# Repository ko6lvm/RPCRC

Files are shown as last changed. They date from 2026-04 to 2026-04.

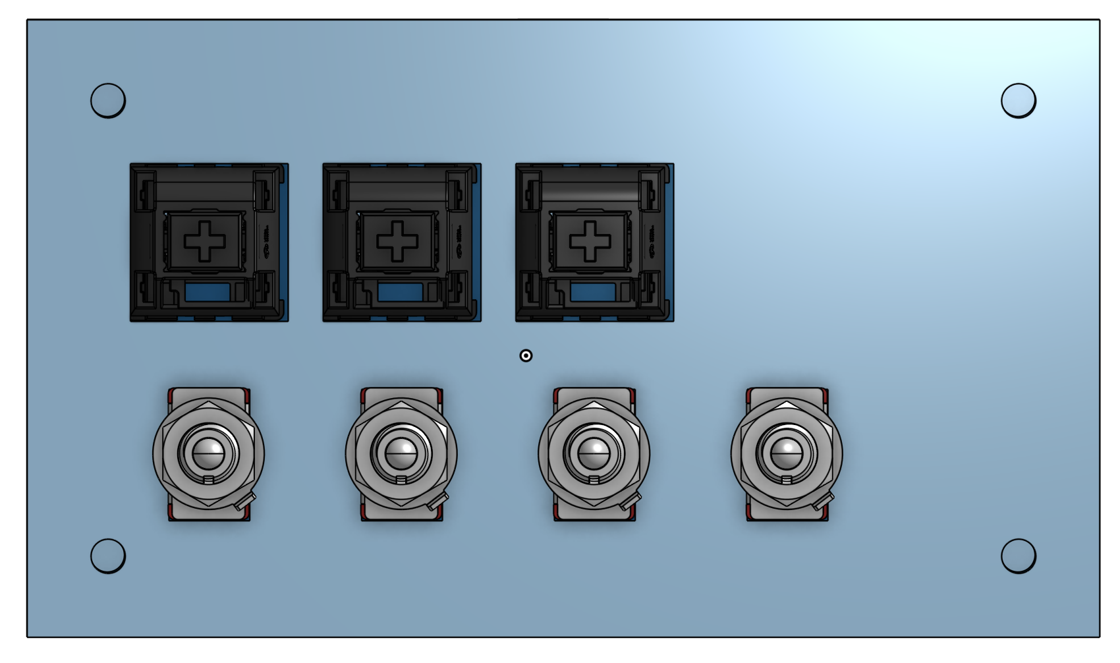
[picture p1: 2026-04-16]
img/assembly_top.png

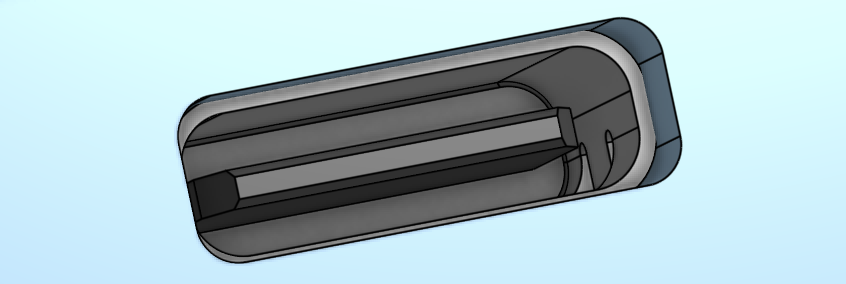
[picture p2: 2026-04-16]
img/assembly_usbc.png

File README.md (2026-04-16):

# RPCRC
A sleek and multi-use PTT and voice switch for Discord and VATSIM's Consolidated Radar Client.

<image src="img/cover_close.png" style="height: 200px;">

### Function
A PTT for CRC, a PTT for Discord, and a Toggle Deafen for Discord, as well as RX, SPKR, XC, and XCA switches for CRC's AFV Voice Switch.
### Motive
I don't want to give up my right Alt / Ctrl keys on my keyboard for VATSIM controlling, so I made this with some extra switches.
## Features
* 3 Dedicated MX Switches for PTT and Deafen Toggles
* 4 Dedicated On-Off Switches for RX, SPKR, XC, and XCA Toggles in CRC
<sup>(INOP of 4/2026 due to CRC AFV Restrictions)</sup>
* 3 Green, Blue, and Red LEDs for PTT and Deafen Visual Signaling
* Custom Board with RP2040
* Custom KMK Firmware for ARM Cortex-M0+ on CircuitPython

<sup>(yes, this is a bit exaggerated)</sup>

## CAD
RPCRC is modeled in OnShape. STEPs and GLTFs are available.

## PCB
The Gerber ZIP (`RPCRCv1Final.zip`) and a standard STEP file (`pcb.step`) including sample parts are available.

## Firmware
RPCRC runs on KMK commit `8afe569` with CircuitPython `v10.2.0-alpha.1`.
#### Code `RPCRC/firmware/src/code.py`

#### Upload Files `RPCRC/firmware/upload`

#### KMK `RPCRC/firmware/kmk`

#### CircuitPython `RPCRC/firmware/cpy`

## Images

### PCB
<image src="img/pcb_3d_side.png" style="height: 200px;">

<image src="img/pcb_final.png" style="height: 200px;">

<image src="img/pcb_editor_view.png" style="height: 200px;">

### PCB with Components
<image src="img/pcb_3d_model_side.png" style="height: 200px;">

### Case and Lid
#### Flat Case
<image src="img/cad_case.png" style="height: 200px;">

#### Angled Case (13.85°)
<image src="img/cad_angled_case.png" style="height: 200px;">

#### Lid
<image src="img/cad_lid.png" style="height: 200px;">

### Final Product
#### Standard
<image src="img/assembly_left.png" style="height: 200px;">

<image src="img/assembly_side_angle.png" style="height: 200px;">

<image src="img/assembly_top.png" style="height: 200px;">

#### Angled
<image src="img/assembly_angle_right.png" style="height: 200px;">

<image src="img/assembly_angle_side.png" style="height: 200px;">

## BoM
_Also available in .CSV format in `RPCRC/bom.csv`._

**Subtotal $29.88**
| Name | Purpose | Quantity | Total Cost (USD) | Link | Distributor |
| :--- | :--- | :---: | :---: | :--- | :--- |
| SMD Stencil | Single Side | 1 | 3.05 | [Link](https://jlcpcb.com) | JLCPCB |
| PCB | FR4 Blue Min 5 | 5 | 4.00 | [Link](https://jlcpcb.com) | JLCPCB |
| 10 R0603 | C109318 Min 100 | 100 | 0.40 | [Link](https://www.lcsc.com/product-detail/C109318.html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) | LCSC |
| 100 R0603 | C105588 Min 100 | 100 | 0.14 | [Link](https://www.lcsc.com/product-detail/C105588.html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) | LCSC |
| Green L0603 | C965804 Min 100 | 100 | 0.51 | [Link](https://www.lcsc.com/product-detail/C965804.html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) | LCSC |
| Blue L0603 | C965807 Min 100 | 100 | 0.42 | [Link](https://www.lcsc.com/product-detail/C965807.html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) | LCSC |
| Red L0603 | C965799 Min 100 | 100 | 0.38 | [Link](https://www.lcsc.com/product-detail/C965799.html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) | LCSC |
| 27 R0603 | C2907021 Min 100 | 100 | 0.10 | [Link](https://www.lcsc.com/product-detail/C2907021.html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) | LCSC |
| 1K R0603 | C22548 Min 100 | 100 | 0.15 | [Link](https://www.lcsc.com/product-detail/C22548.html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) | LCSC |
| 15pF C0603 | C1644 Min 100 | 100 | 0.54 | [Link](https://www.lcsc.com/product-detail/C1644.html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) | LCSC |
| 10K R0603 | C98220 Min 100 | 100 | 0.15 | [Link](https://www.lcsc.com/product-detail/C98220.html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) | LCSC |
| 5.1K R0603 | C2907044 Min 100 | 100 | 0.12 | [Link](https://www.lcsc.com/product-detail/C2907044.html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) | LCSC |
| 10uF C0603 | C19702 Min 50 | 50 | 0.40 | [Link](https://www.lcsc.com/product-detail/C19702.html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) | LCSC |
| 0.1uF C0603 | C1591 Min 100 | 100 | 0.28 | [Link](https://www.lcsc.com/product-detail/C1591.html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) | LCSC |
| 1uF C0603 | C15849 Min 50 | 50 | 0.39 | [Link](https://www.lcsc.com/product-detail/C15849.html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) | LCSC |
| Pushbutton | C49234152 Min 20 | 20 | 0.64 | [Link](https://www.lcsc.com/product-detail/C49234152.html?s_z=n_C49234152) | LCSC |
| On-Off Switch | C1788492 | 10 | 5.16 | [Link](https://www.lcsc.com/product-detail/C1788492.html) | LCSC |
| RP2040 | C2040 | 5 | 4.74 | [Link](https://www.lcsc.com/product-detail/C2040.html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) | LCSC |
| 16MB Flash | C2062840 | 5 | 5.52 | [Link](https://www.lcsc.com/product-detail/C2062840.html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) | LCSC |
| 3.3V LDO | C51118 Min 5 | 5 | 0.73 | [Link](https://www.lcsc.com/product-detail/C51118.html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) | LCSC |
| USB-C 16pin | C2765186 Min 20 | 20 | 1.33 | [Link](https://www.lcsc.com/product-detail/C2765186.html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) | LCSC |
| 12MHz Crystal | C9002 Min 10 | 10 | 0.73 | [Link](https://www.lcsc.com/product-detail/C9002.html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) | LCSC |

_Excludes applicable tax, shipping, and tools._

## Copyright
**Copyright 2026 Jeongwoo "Ryan" Kim KO6LVM. All rights reserved.**

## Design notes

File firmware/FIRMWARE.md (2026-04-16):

# RPCRC/firmware/src
This directory includes the code written by KO6LVM that is built from CircuitPython and KMK.

# RPCRC/firmware/upload
This directory includes all files that should be uploaded into the RP2040 board after flashing the UF2.

# RPCRC/firmware/kmk
This directory is the source for the KMK CircuitPython package. It includes the latest release, commit 8afe569.

The package included is directly from the KMK Github. The latest version can be downloaded at https://github.com/KMKfw/kmk_firmware.

All firmware copyright KMKfw 2026.

# RPCRC/firmware/cpy
This directory includs CircuitPython v10.2.0-alpha.1 for the RP2040/Pi Pico.

The firmware included is directly from CircuitPython. The latest version can be downloaded at https://circuitpython.org/board/raspberry_pi_pico/. To install, drag-and-drop the uf2 file into your RP2040 Mass Storage device in BOOTSEL mode.

All firmware copyright Adafruit Industries 2026.

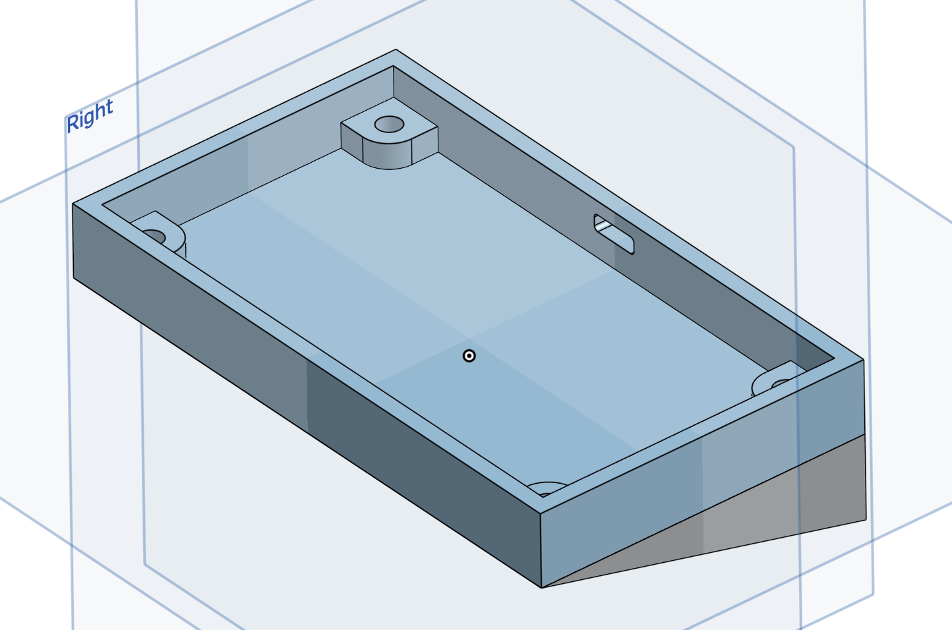
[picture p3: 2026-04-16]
img/cad_angled_case.png

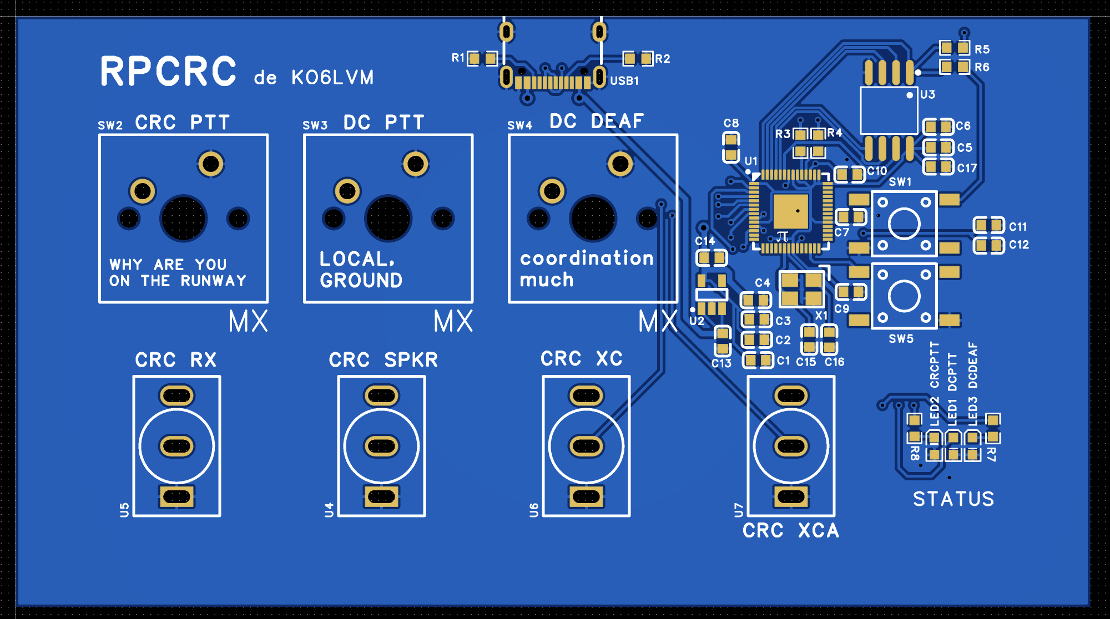
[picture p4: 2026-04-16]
img/pcb_final.png

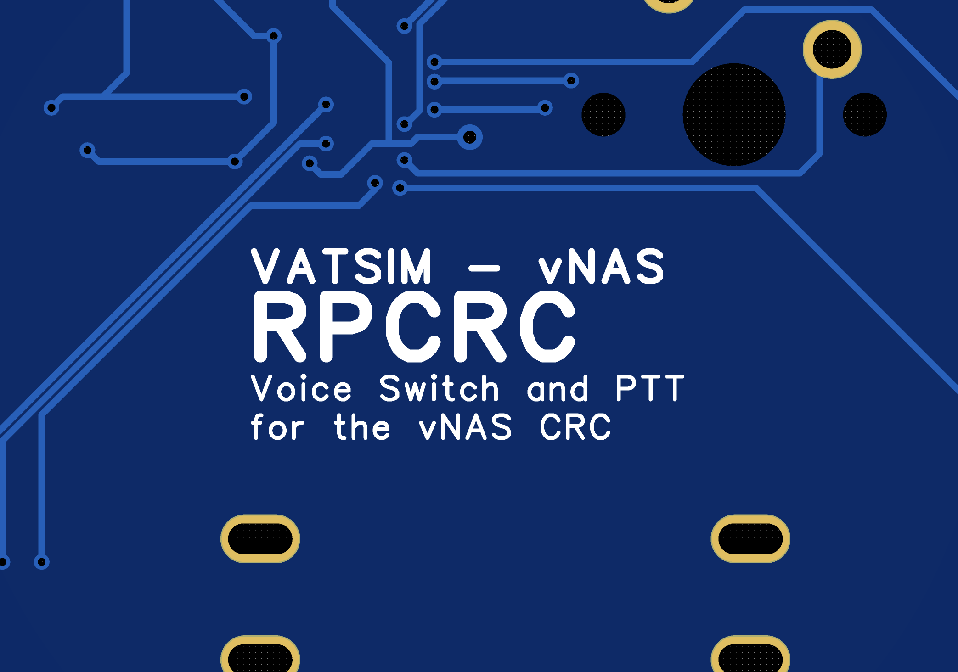
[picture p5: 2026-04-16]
img/cover_far.png

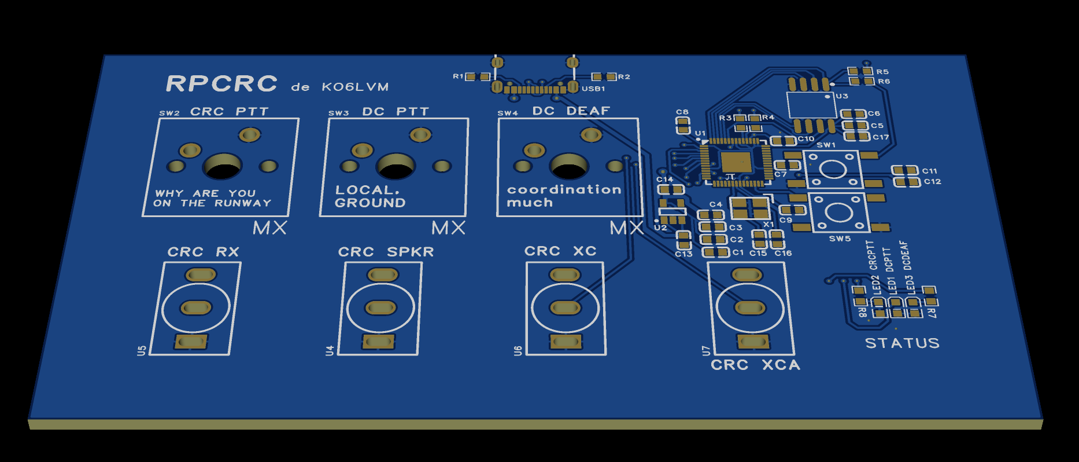
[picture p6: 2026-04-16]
img/pcb_3d_side.png

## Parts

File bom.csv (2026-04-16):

Name | Purpose | Quantity | Total Cost (USD) | Link | Distributor
16MB Flash | C2062840 | 5 | 5.52 | https://www.lcsc.com/product-detail/C2062840.html?s_z=n_16MB | LCSC
SMD Stensil | Single Side | 1 | 3.05 | https://jlcpcb.com | JLCPCB
PCB | FR4 Blue Min 5 | 5 | 4.00 | https://jlcpcb.com | JLCPCB
10 R0603 | C109318 Min 100 | 100 | 0.40 | https://www.lcsc.com/product-detail/C109318.html?s_z=n_10ohm%25200603 | LCSC
100 R0603 | C105588 Min 100 | 100 | 0.14 | https://www.lcsc.com/product-detail/C105588.html?s_z=n_100%2520ohm%2520r0603 | LCSC
Green L0603 | C965804 Min 100 | 100 | 0.51 | https://www.lcsc.com/product-detail/C965804.html | LCSC
Blue L0603 | C965807 Min 100 | 100 | 0.42 | https://www.lcsc.com/product-detail/C965807.html | LCSC
Red L0603 | C965799 Min 100 | 100 | 0.38 | https://www.lcsc.com/product-detail/C965799.html?s_z=n_red%2520led | LCSC
27 R0603 | C2907021 Min 100 | 100 | 0.10 | https://www.lcsc.com/product-detail/C2907021.html?s_z=n_27%2520ohm%25200603 | LCSC
1K R0603 | C22548 Min 100 | 100 | 0.15 | https://www.lcsc.com/product-detail/C22548.html?s_z=n_1K%2520R0603 | LCSC
15pF C0603 | C1644 Min 100 | 100 | 0.54 | https://www.lcsc.com/product-detail/C1644.html?s_z=n_15pF%2520C0603 | LCSC
10K R0603 | C98220 Min 100 | 100 | 0.15 | https://www.lcsc.com/product-detail/C98220.html?s_z=n_10K%2520R0603 | LCSC
5.1K R0603 | C2907044 Min 100 | 100 | 0.12 | https://www.lcsc.com/product-detail/C2907044.html?s_z=n_5.1K%2520R0603 | LCSC
10uF C0603 | C19702 Min 50 | 50 | 0.40 | https://www.lcsc.com/product-detail/C19702.html?s_z=n_10uF%2520C0603 | LCSC
0.1uF C0603 | C1591 Min 100 | 100 | 0.28 | https://www.lcsc.com/product-detail/C1591.html?s_z=n_0.1uF%2520C0603 | LCSC
1uF C0603 | C15849 Min 50 | 50 | 0.39 | https://www.lcsc.com/product-detail/C15849.html?s_z=n_1uF%25200603 | LCSC
Pushbutton | C49234152 Min 20 | 20 | 0.64 | https://www.lcsc.com/product-detail/C49234152.html?s_z=n_C49234152 | LCSC
On-Off Switch | C1788492 | 10 | 5.16 | https://www.lcsc.com/product-detail/C1788492.html | LCSC
RP2040 | C2040 | 5 | 4.74 | https://www.lcsc.com/product-detail/C2040.html?s_z=n_RP2040 | LCSC
3.3V LDO | C51118 Min 5 | 5 | 0.73 | https://www.lcsc.com/product-detail/C51118.html?s_z=n_AP2112K-3.3TRG1 | LCSC
USB-C 16pin | C2765186 Min 20 | 20 | 1.33 | https://www.lcsc.com/product-detail/C2765186.html?s_z=n_TYPE-C%252016PIN%25202MD%28073%29 | LCSC
12MHz Crystal | C9002 Min 10 | 10 | 0.73 | https://www.lcsc.com/product-detail/C9002.html?s_z=n_12mhz | LCSC

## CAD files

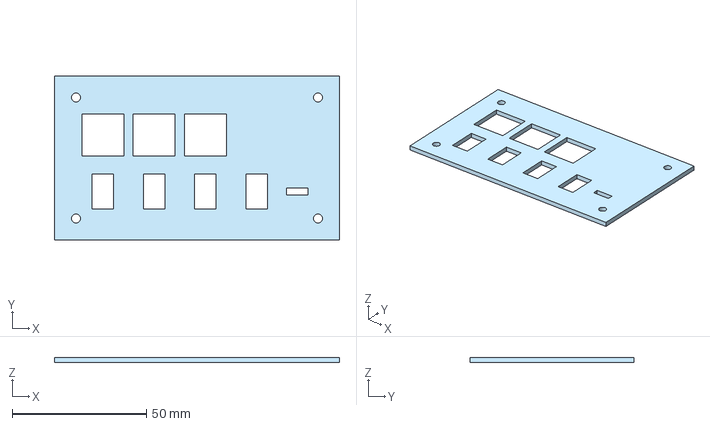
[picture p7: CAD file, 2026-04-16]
cad/step/lid.step
106.0 x 61.0 x 2.00 mm

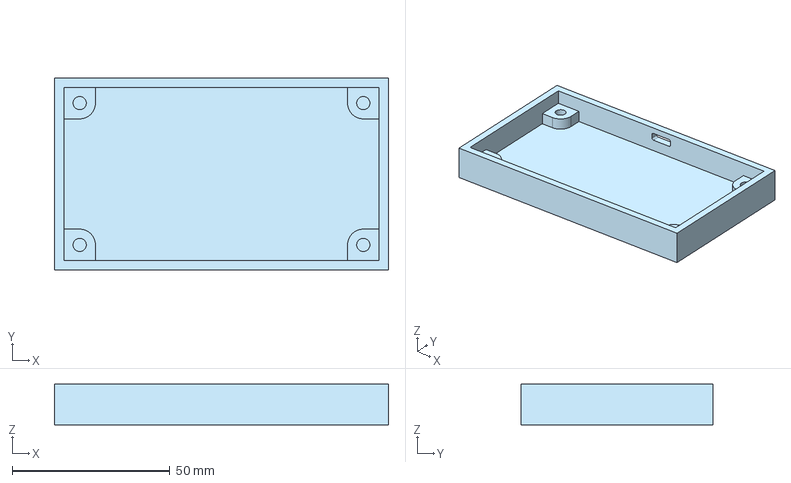
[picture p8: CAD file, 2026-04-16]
cad/step/standard_case.step
106.0 x 61.0 x 13.0 mm

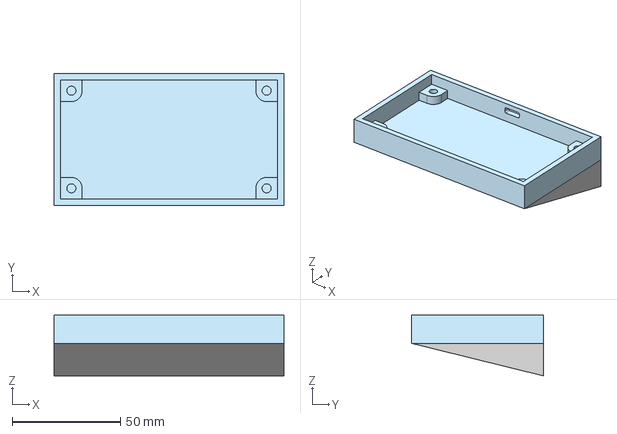
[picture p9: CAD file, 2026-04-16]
cad/step/angled_case.step
106.0 x 61.0 x 28.0 mm

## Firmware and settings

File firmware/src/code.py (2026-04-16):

# CODE.PY
# COPYRIGHT 2026 JEONGWOO "RYAN" KIM KO6LVM

import board
import digitalio
from kmk.kmk_keyboard import KMKKeyboard
from kmk.keys import KC
from kmk.scanners.keypad import KeysScanner

keyboard = KMKKeyboard()

# 1. Setup LEDs as standard digital outputs
led7 = digitalio.DigitalInOut(board.GP7)
led7.direction = digitalio.Direction.OUTPUT

led8 = digitalio.DigitalInOut(board.GP8)
led8.direction = digitalio.Direction.OUTPUT

led9 = digitalio.DigitalInOut(board.GP9)
led9.direction = digitalio.Direction.OUTPUT

# Pin setup
# Value When Pressed is key reading when key is pressed,
# therefore False is when key is GROUNDed.
keyboard.matrix = KeysScanner(
    pins=[
        board.GP0, board.GP5, board.GP6,
        board.GP1, board.GP2, board.GP3, board.GP4
    ],
    value_when_pressed=False, 
)

# PTTLED 7 DCPTTLED 8 DCDEAFLED 9

# Keymap
keyboard.keymap = [
    [
        KC.F18, KC.F19, KC.F20,  # GP0, GP1, GP2 MX
        KC.F21,   KC.F22,   KC.F23, KC.F24 # GP3, GP4, GP5, GP6 On/Off
    ]
]


gp9_toggle_state = False
last_gp2_state = False

def led_logic(keyboard):
    global gp9_toggle_state, last_gp2_state

    # GP7 - GP0 Button - follows button status
    led7.value = keyboard.matrix.states[0]

    # GP8 - GP1 Button - follows button status
    led8.value = keyboard.matrix.states[1]

    # GP9 - GP2 Button - toggled
    current_gp2_state = keyboard.matrix.states[2]
    if current_gp2_state and not last_gp2_state:
        gp9_toggle_state = not gp9_toggle_state
    
    led9.value = gp9_toggle_state
    last_gp2_state = current_gp2_state

keyboard.before_matrix_scan.append(led_logic)

if __name__ == '__main__':
    keyboard.go()

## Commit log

2026-04-16 Mass upload of images, STEPs, firmware, etc.
    [angled_case.step, lid.step, standard_case.step]
2026-04-16 BoM, Flash fix
    [bom.csv]
2026-04-16 Fix lid to include holes for LEDs
    [lid.step]
